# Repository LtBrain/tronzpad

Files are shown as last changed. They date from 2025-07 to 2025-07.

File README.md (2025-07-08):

# **Tronzpad**
Tronzpad is a 12 key + 1 encoder macropad that has 12 individually addressable LEDs to provide underglow & backlighting.
It was developed for an entry for **Hackclub Highway**'s YSWS project (Hackpad) and has the ability to perform **macros** and other
cool stuff with VIAL & QMK.

tronzpad 1 (1)

## Features
   - [x] **12 Cherry MX switches**  
   - [x] **EC-11 Rotary Encoder + Push Button**  
   - [x] **12 Individually Adressable SK6812 MINI LEDs**  
   - [x] **Custom QMK and VIAL Features**  
   - [x] **Powered By A XIAO RP2040**

## PCB

All of the circuitry and PCB design was done with KiCAD 8.0 on Windows 11

#### Schematic

tronzpad_sch-1  

#### PCB Design



Credits to Joe Scotto for the footprints.

## Firmware

QMK and VIAL are meant to be used on Tronzpad for firmware.
   - [x] **Customizable keymap and layout**
   - [x] **12 keys for macros**
   - [x] **Compilable with QMK MSYS on Win11 and Linux (MacOS not tested)**
   - [x] **Real-time/On the fly configuration**
   - [x] **Layer Switching**  
### **How to Compile the Firmware**  
```qmk compile -kb tronzpad -km default```  
  
Paste this into a **MSYS** terminal on Windows or into a Linux terminal with **QMK** already setup.  
(You have to be in the **directory** for this to work)

## Case Assembly
   The case for the Tronzpad was designed to be minimalistic, exposing the graphics on the PCB silkscreen. It is composed of two 3D printed parts, a plate piece and the main assembly.
   The case has 4 2.9mm holes designed to accommodate M3 screws to hold the PCB in place. The plate sits on top of the PCB's top layer to provide a cosmetic/semi-functional layer for 
   the switches to be seated in. 

   ### Plate
   ![tronzpad 1 (2)](https://github.com/user-attachments/assets/d26cf02f-f786-46ef-9ef3-2593b20badfe)

   ### Main Case
   ![tronzpad 1 (3)](https://github.com/user-attachments/assets/5db9a6ba-11bc-4787-be42-7c94eafe2cd0)

## Bill of Materials  

| Quantity | Component | Description |
| --- | --- | --- |
| `1` | **Seeed Studio XIAO RP2040** | MCU |
| `12` | **Cherry MX Keyswitches** | I/O |
| `1` | **EC11 Rotary Encoder** | I/O |
| `13` | **1N4148 Diodes** | Support |
| `15` | **SK6812 MINI LEDs** | I/O | 
| `12` | **DSA Keycaps** | Support |
| `4` | **M3x16mm Screws**| Support |
| `1` | **Case Plate**| Support |
| `1` | **Main Case**| Support |
| `1` | **PCB (From JLCPCB)**| Circuit |  

**Summer, 2025**

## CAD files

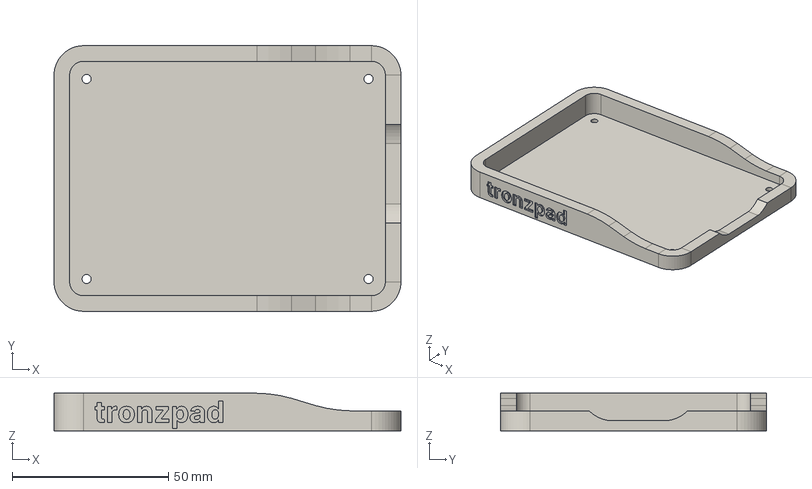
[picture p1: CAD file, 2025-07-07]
Production/tronzpad_main_case.step
111.0 x 85.0 x 12.0 mm

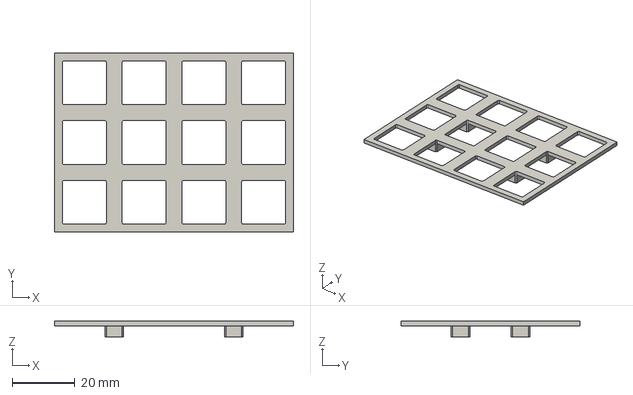
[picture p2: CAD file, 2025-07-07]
Production/tronzpad_plate.step
76.2 x 57.1 x 5.00 mm

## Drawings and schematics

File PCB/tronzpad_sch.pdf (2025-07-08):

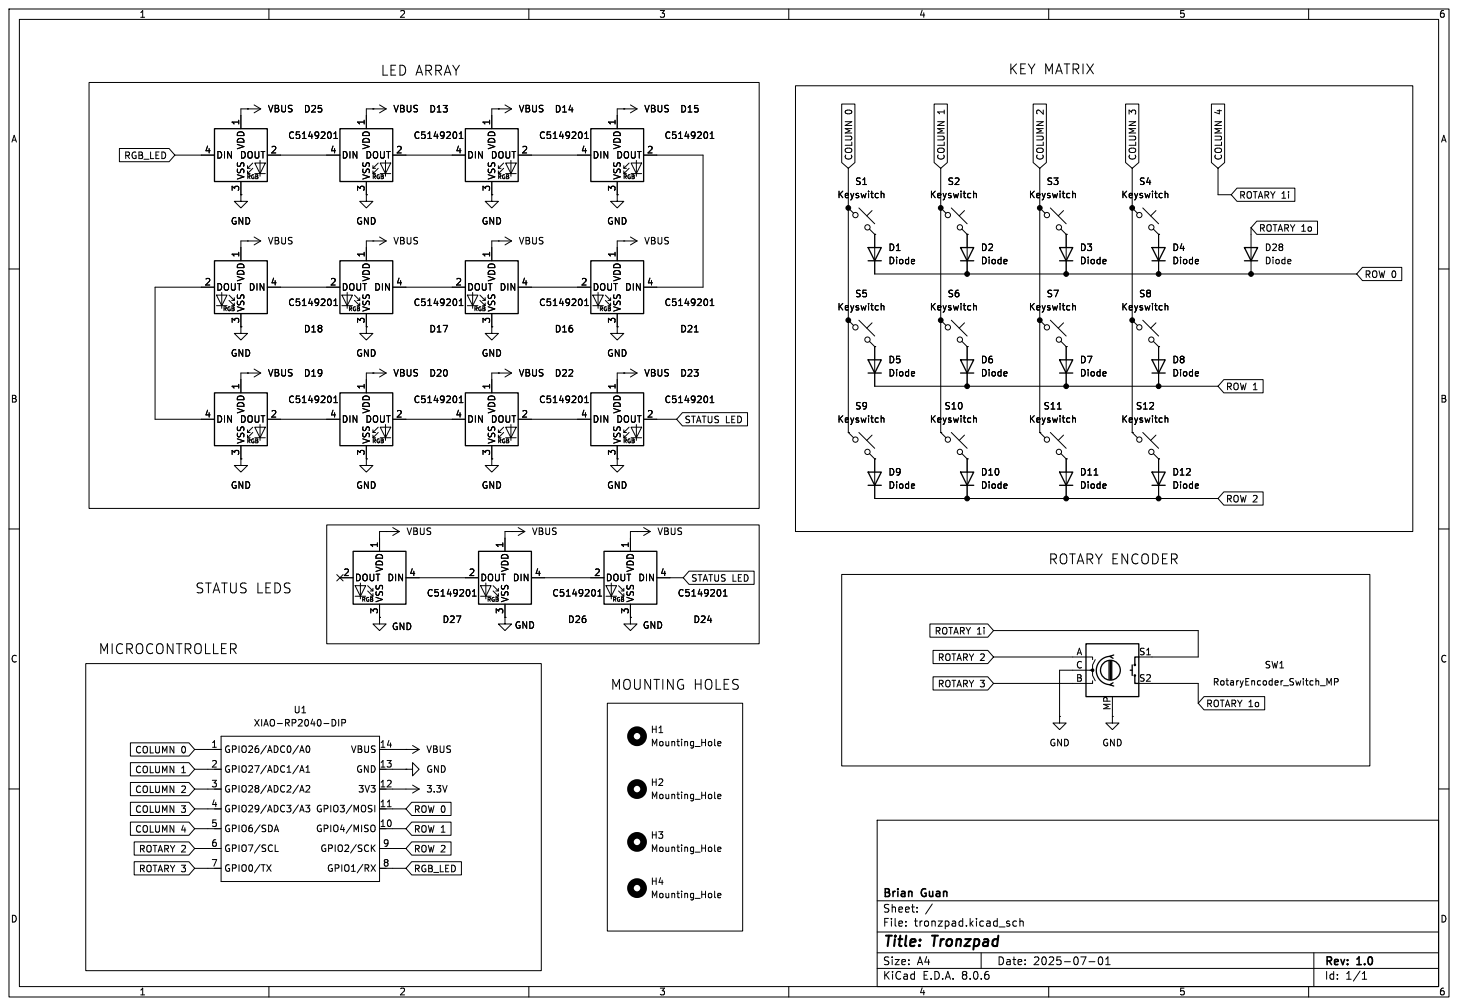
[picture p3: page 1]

3 DIN 4 D22 C5149201 S7 Keyswitch S8 Keyswitch COLUMN 1 ROTARY 3 ROTARY 2 COLUMN 4 COLUMN 3 COLUMN 4 ROW 0 ROW 2 COLUMN 3 COLUMN 1 COLUMN 2 COLUMN 0

3 DIN 4 D13 C5149201 D2 Diode S2 Keyswitch D28 Diode GND

3 DIN 4 D26 C5149201 GND GND GND GND

3 DIN 4 GND GND GND GND D26 C5149201 VDD

File: tronzpad.kicad_sch Sheet: / Brian Guan

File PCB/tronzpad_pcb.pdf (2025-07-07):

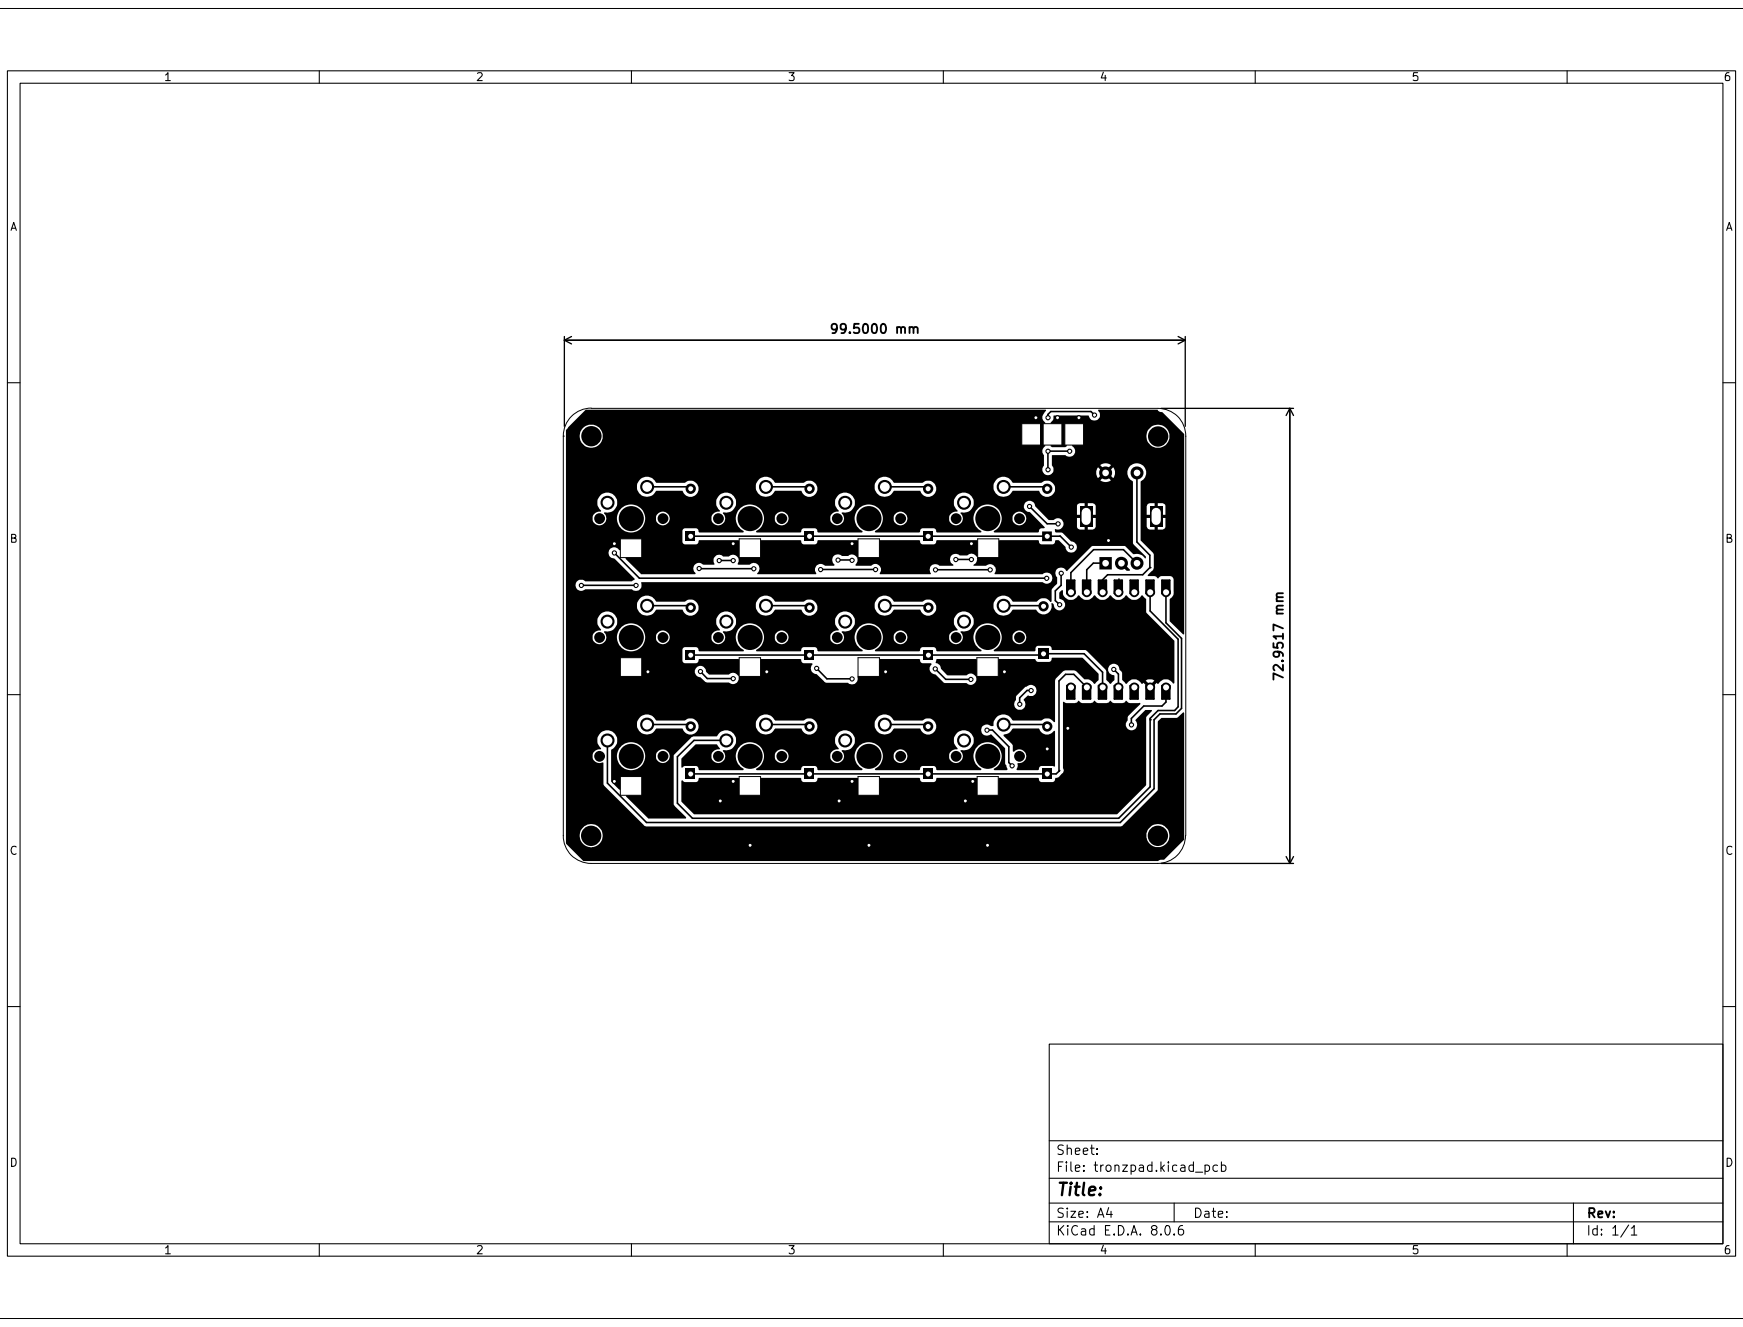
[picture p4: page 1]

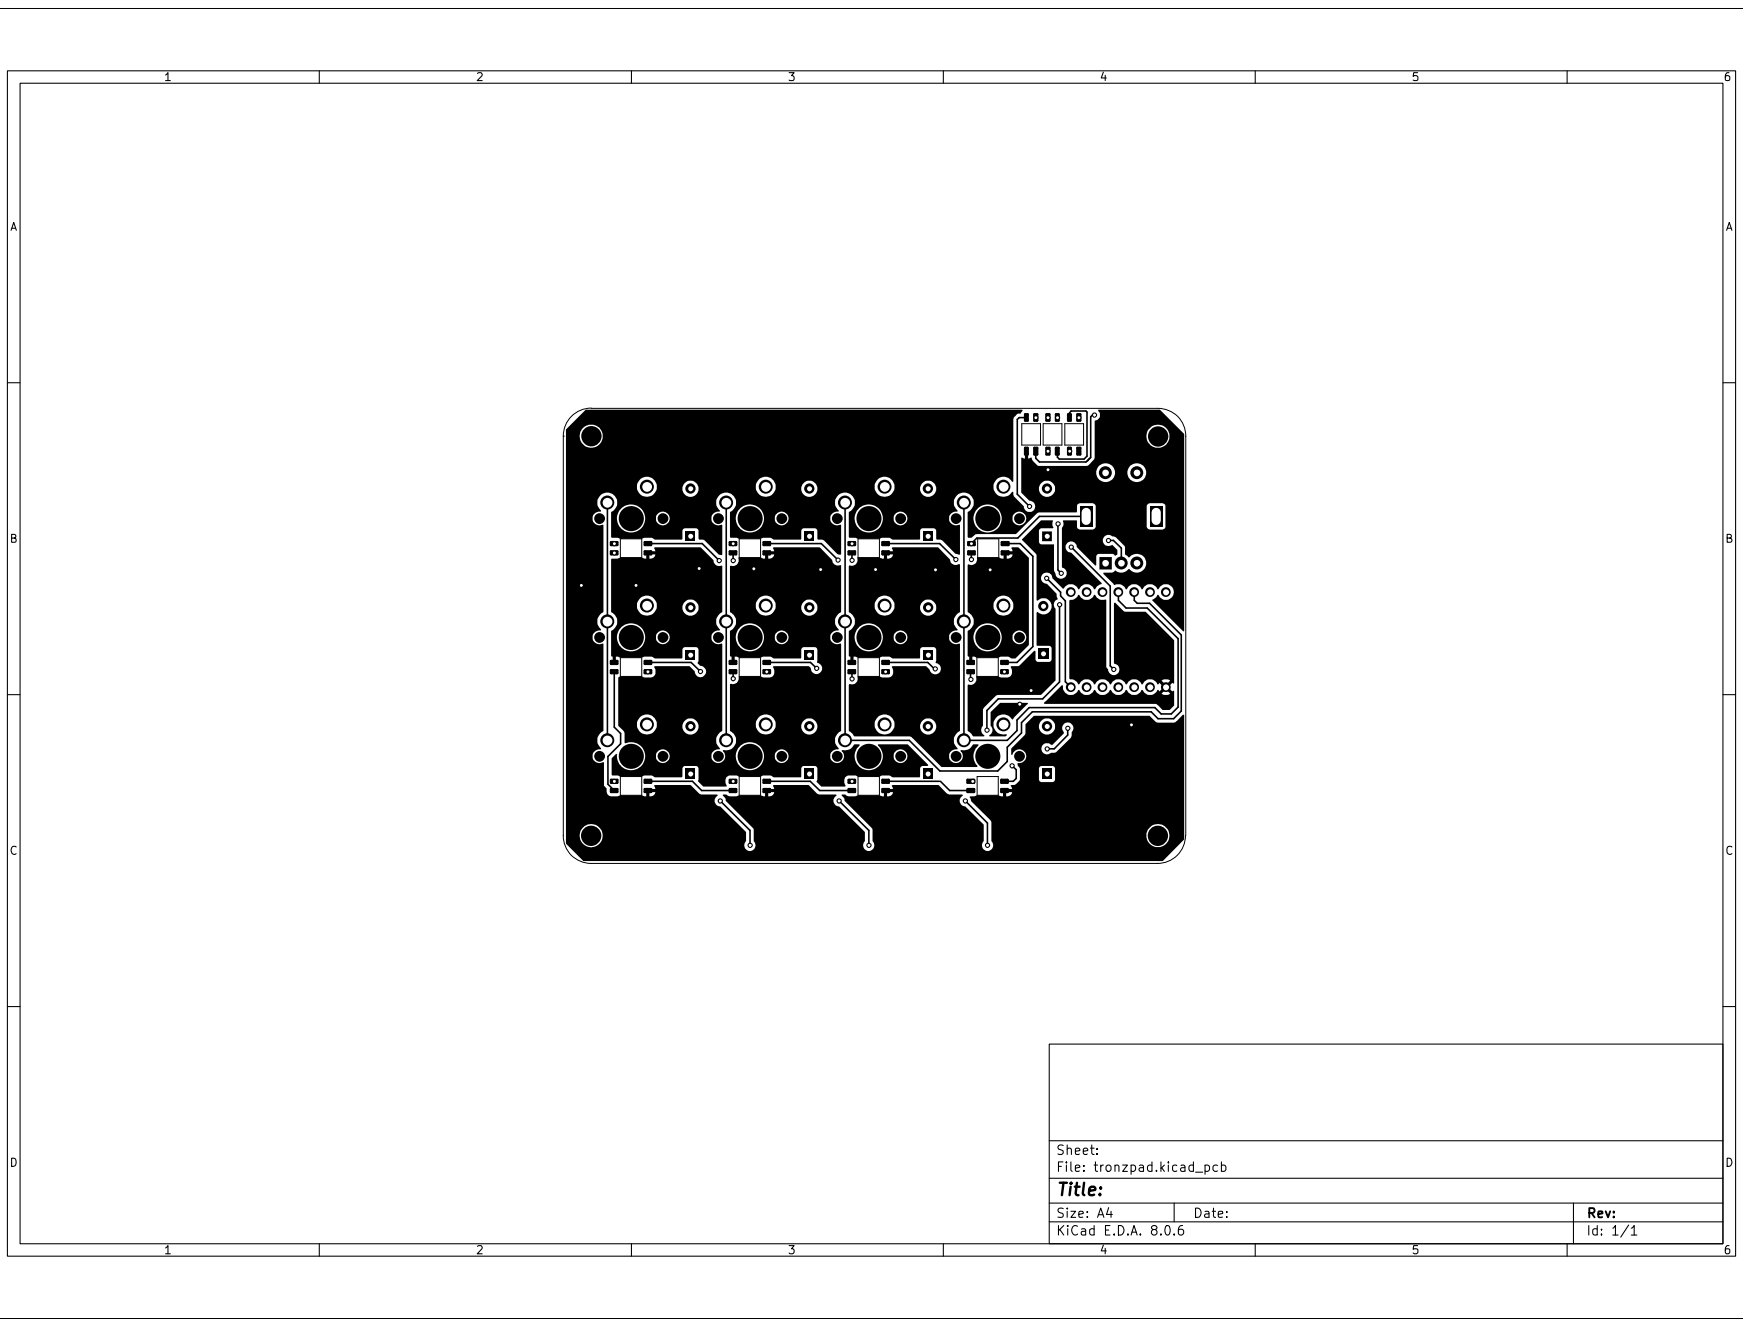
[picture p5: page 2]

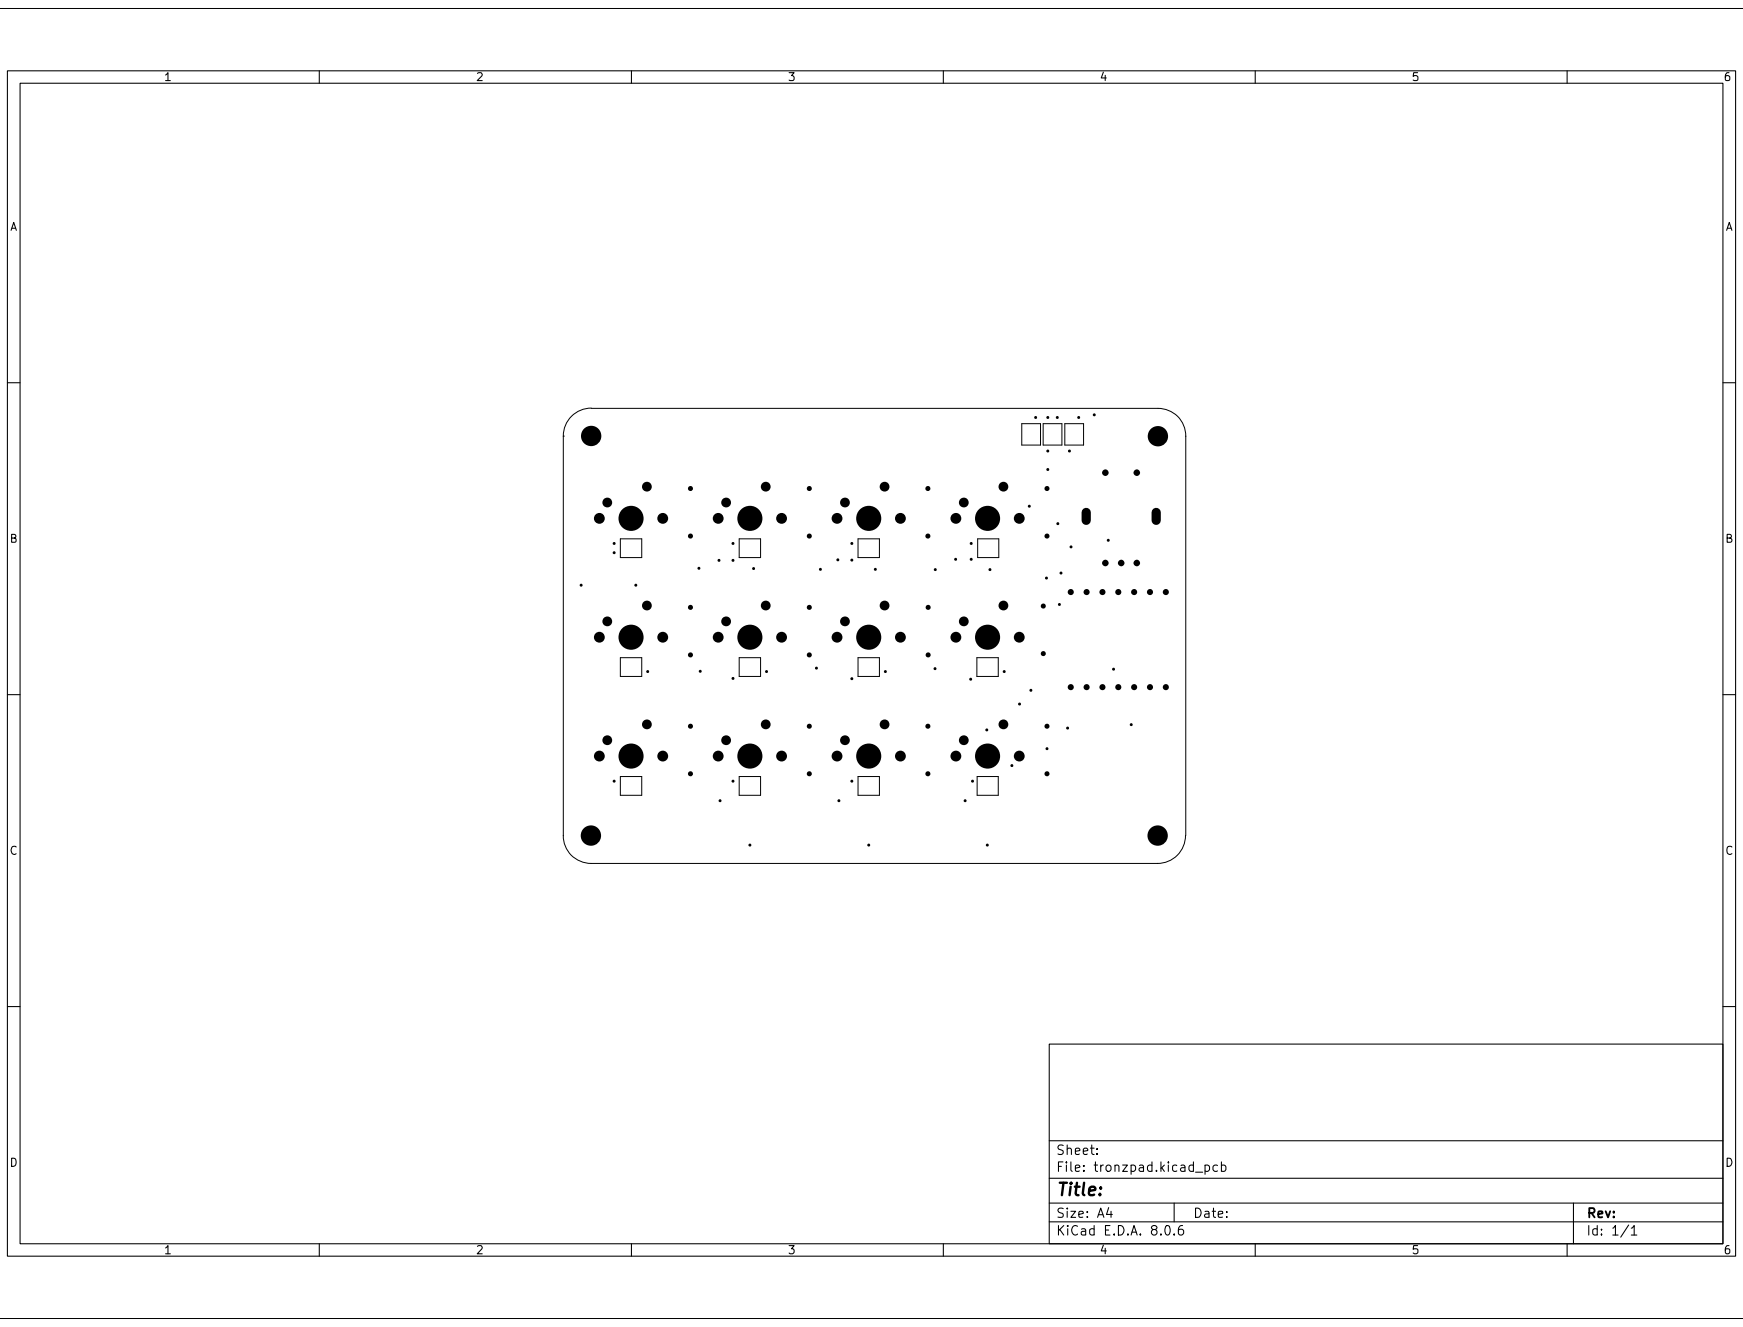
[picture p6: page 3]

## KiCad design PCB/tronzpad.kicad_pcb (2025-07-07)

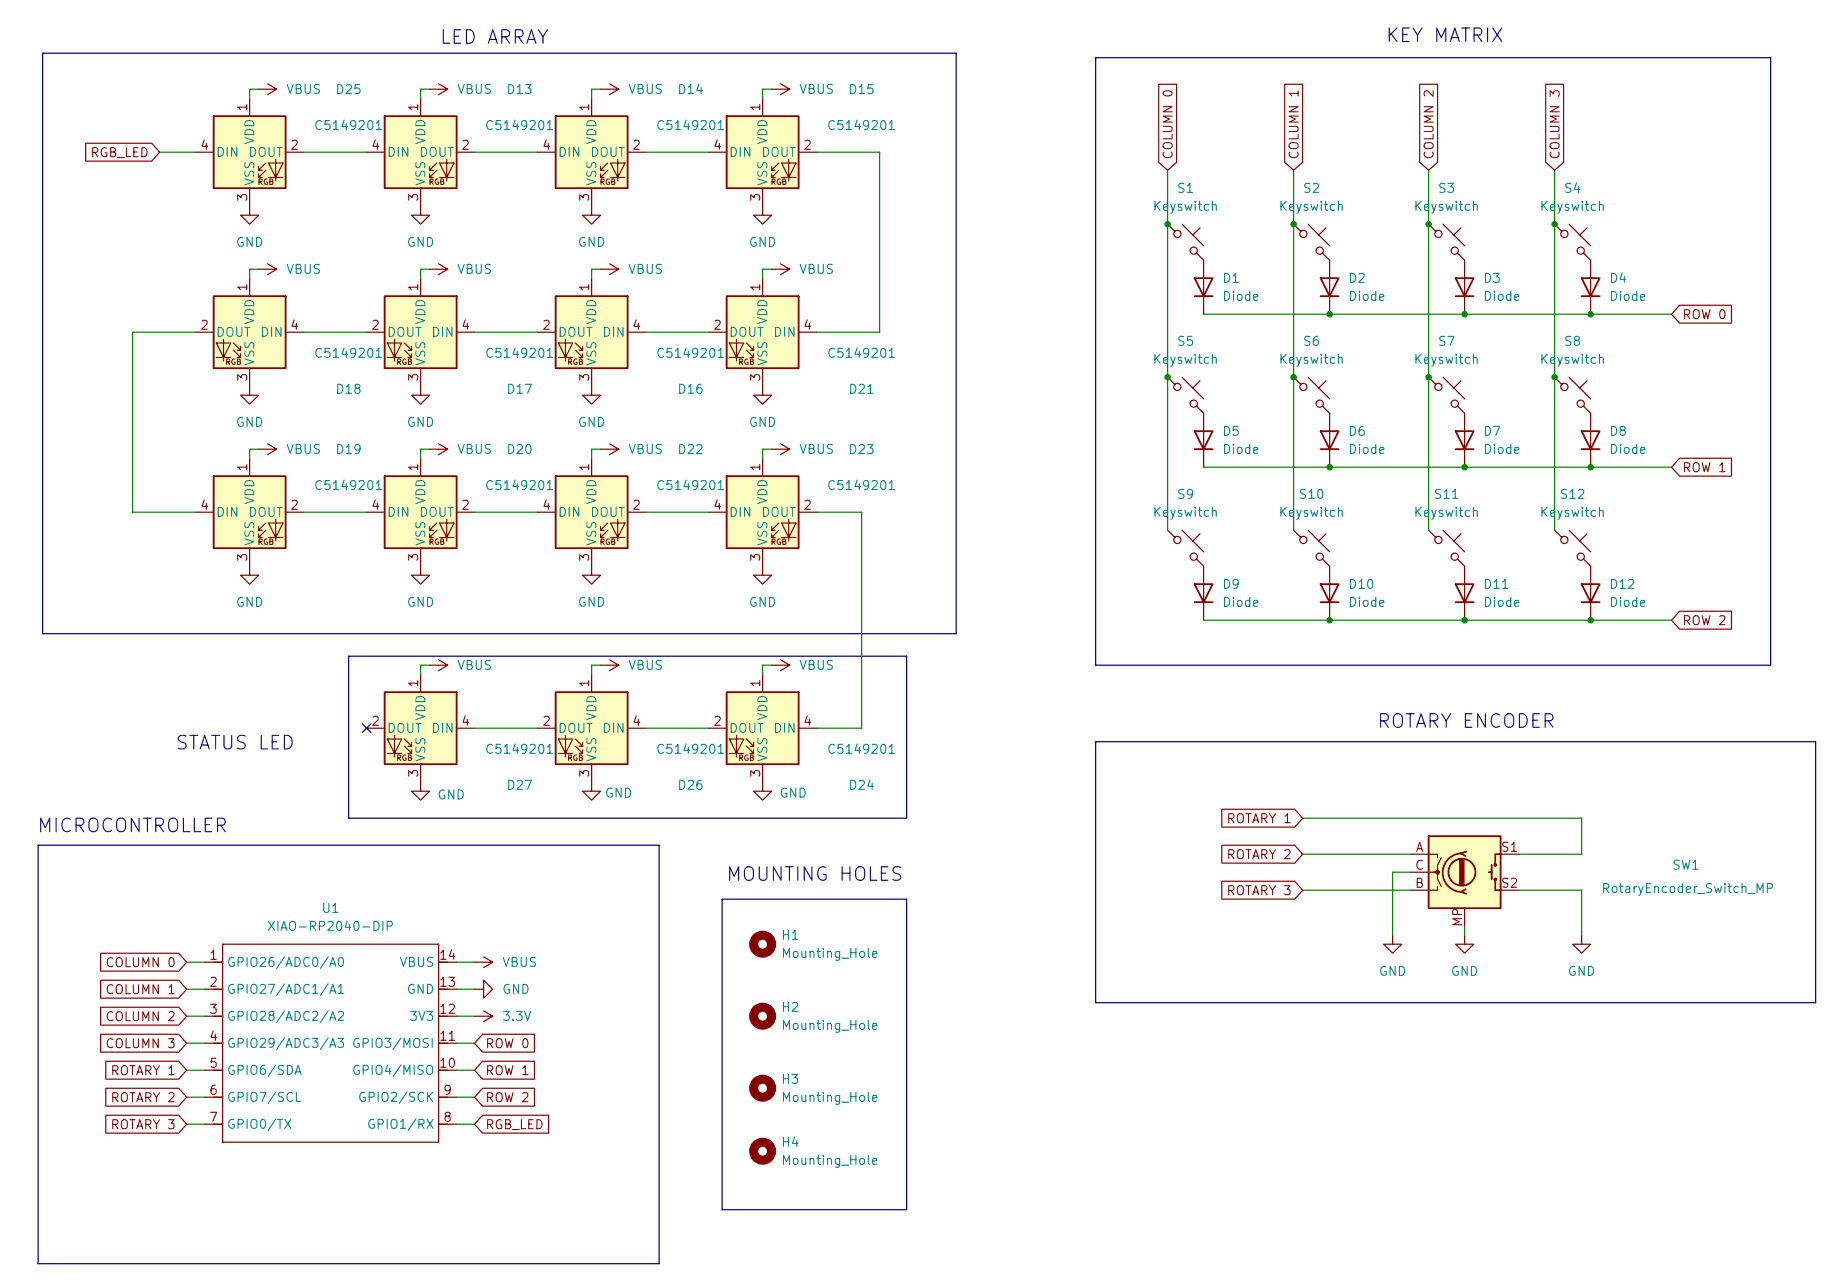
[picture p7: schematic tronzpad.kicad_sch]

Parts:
D1, D2, D3, D4, D5, D6, D7, D8, D9, D10, D11, D12: Diode; D_DO-35_SOD27_P7.62mm_Horizontal
D13, D14, D15, D16, D17, D18, D19, D20, D21, D22, D23, D24, D25, D26, D27: LED_SK6812MINI; LCSC C5149201
H1, H2, H3, H4: Mounting_Hole; MountingHole_3.2mm_M3_DIN965
S1, S2, S3, S4, S5, S6, S7, S8, S9, S10, S11, S12: Keyswitch; SW_Cherry_MX_1.00u_PCB
SW1: RotaryEncoder_Switch_MP; RotaryEncoder_Alps_EC11E-Switch_Vertical_H20mm
U1: XIAO-RP2040-DIP

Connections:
3.3V: U1.12 (3V3)
COLUMN 1: S1.2, S5.2, S9.2, U1.1 (GPIO26/ADC0/A0)
COLUMN 2: S2.2, S6.2, S10.2, U1.2 (GPIO27/ADC1/A1)
COLUMN 3: S3.2, S7.2, S11.2, U1.3 (GPIO28/ADC2/A2)
COLUMN 4: S4.2, S8.2, S12.2, U1.4 (GPIO29/ADC3/A3)
GND: D13.3 (VSS), D14.3 (VSS), D15.3 (VSS), D16.3 (VSS), D17.3 (VSS), D18.3 (VSS), D19.3 (VSS), D20.3 (VSS), D21.3 (VSS), D22.3 (VSS), D23.3 (VSS), D24.3 (VSS), D25.3 (VSS), D26.3 (VSS), D27.3 (VSS), SW1.C, SW1.MP, SW1.S2, U1.13 (GND)
unnamed: D1.2 (A), S1.1
unnamed: D2.2 (A), S2.1
unnamed: D3.2 (A), S3.1
unnamed: D4.2 (A), S4.1
unnamed: D5.2 (A), S5.1
unnamed: D6.2 (A), S6.1
unnamed: D7.2 (A), S7.1
unnamed: D8.2 (A), S8.1
unnamed: D9.2 (A), S9.1
unnamed: D10.2 (A), S10.1
unnamed: D11.2 (A), S11.1
unnamed: D12.2 (A), S12.1
unnamed: D13.4 (DIN), D25.2 (DOUT)
unnamed: D13.2 (DOUT), D14.4 (DIN)
unnamed: D14.2 (DOUT), D15.4 (DIN)
unnamed: D15.2 (DOUT), D21.4 (DIN)
unnamed: D16.4 (DIN), D21.2 (DOUT)
unnamed: D16.2 (DOUT), D17.4 (DIN)
unnamed: D17.2 (DOUT), D18.4 (DIN)
unnamed: D18.2 (DOUT), D19.4 (DIN)
unnamed: D19.2 (DOUT), D20.4 (DIN)
unnamed: D20.2 (DOUT), D22.4 (DIN)
unnamed: D22.2 (DOUT), D23.4 (DIN)
unnamed: D23.2 (DOUT), D24.4 (DIN)
unnamed: D24.2 (DOUT), D26.4 (DIN)
unnamed: D26.2 (DOUT), D27.4 (DIN)
RGB_LED: D25.4 (DIN), U1.8 (GPIO1/RX)
ROTARY 1: SW1.S1, U1.5 (GPIO6/SDA)
ROTARY 2: SW1.A, U1.6 (GPIO7/SCL)
ROTARY 3: SW1.B, U1.7 (GPIO0/TX)
ROW 1: D1.1 (K), D2.1 (K), D3.1 (K), D4.1 (K), U1.11 (GPIO3/MOSI)
ROW 2: D5.1 (K), D6.1 (K), D7.1 (K), D8.1 (K), U1.10 (GPIO4/MISO)
ROW 3: D9.1 (K), D10.1 (K), D11.1 (K), D12.1 (K), U1.9 (GPIO2/SCK)
VBUS: D13.1 (VDD), D14.1 (VDD), D15.1 (VDD), D16.1 (VDD), D17.1 (VDD), D18.1 (VDD), D19.1 (VDD), D20.1 (VDD), D21.1 (VDD), D22.1 (VDD), D23.1 (VDD), D24.1 (VDD), D25.1 (VDD), D26.1 (VDD), D27.1 (VDD), U1.14 (VBUS)

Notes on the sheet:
ROTARY ENCODER
LED ARRAY
MOUNTING HOLES
MICROCONTROLLER
STATUS LED
KEY MATRIX

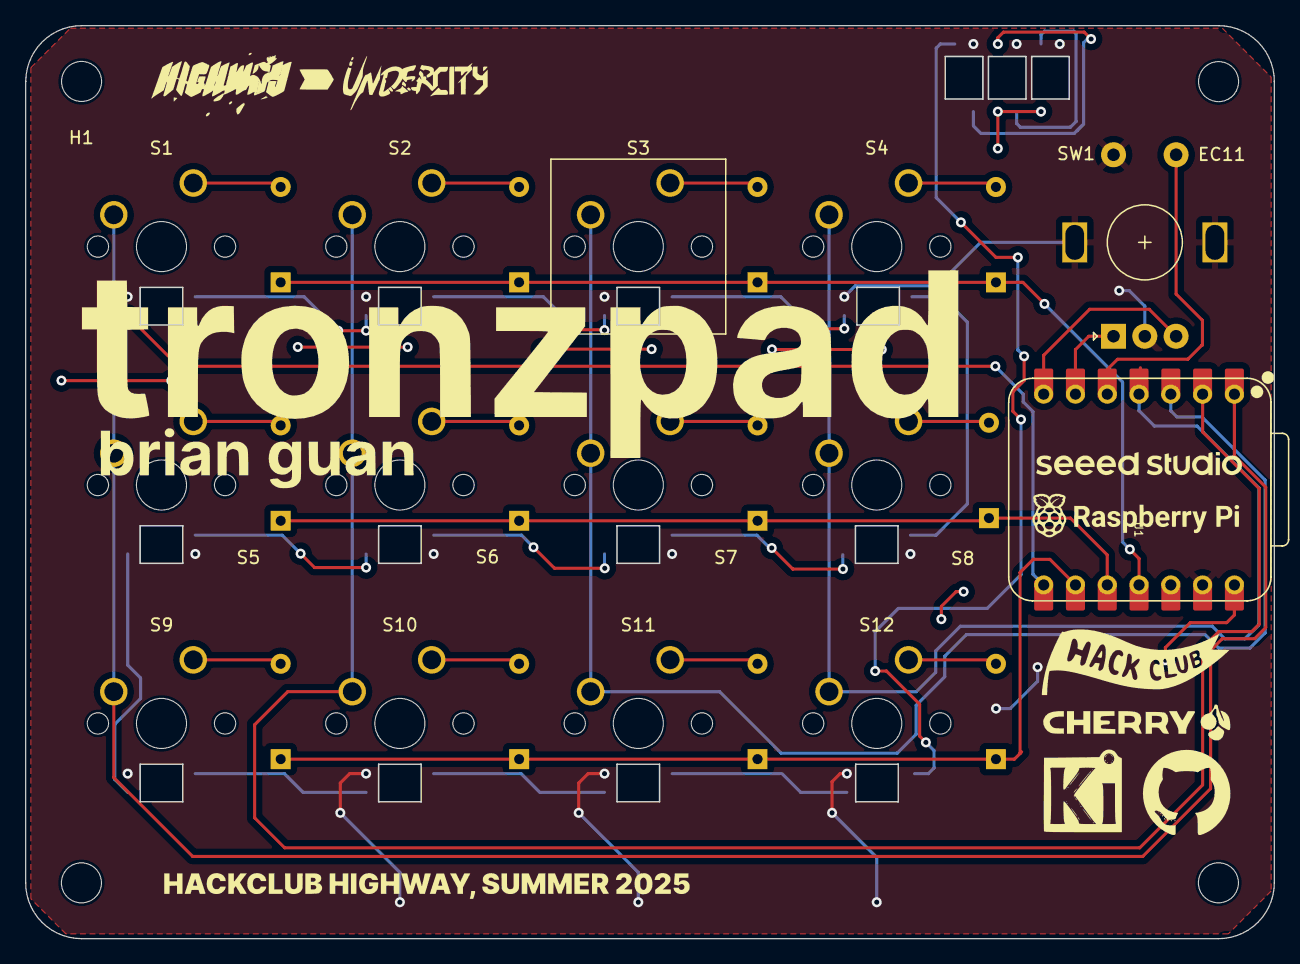
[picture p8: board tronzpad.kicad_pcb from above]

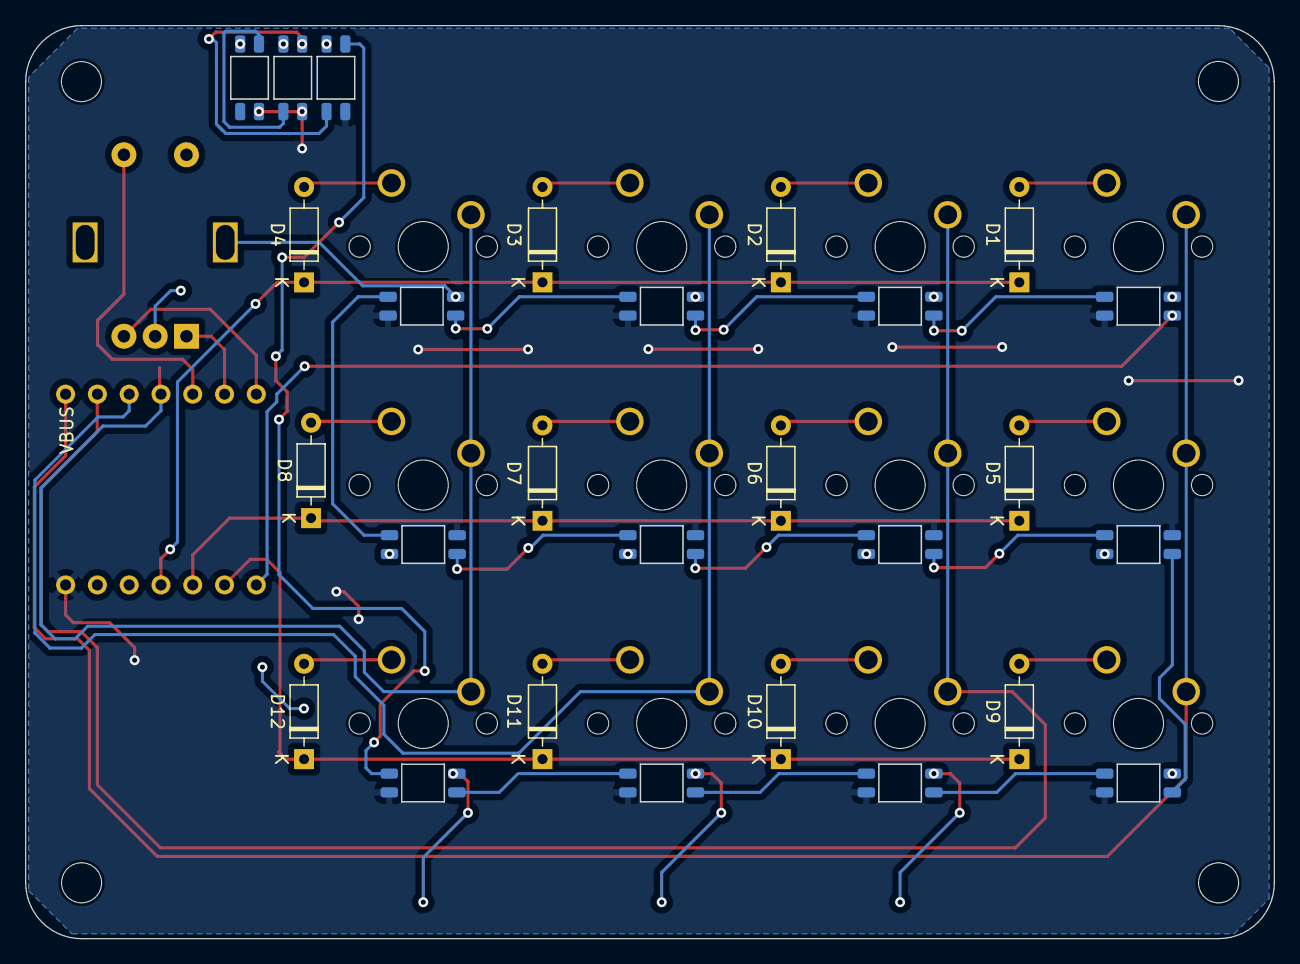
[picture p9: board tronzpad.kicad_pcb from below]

Board: 2 copper layers, 99.8 x 73.0 mm, 45 parts (27 on the bottom side), 39 nets.

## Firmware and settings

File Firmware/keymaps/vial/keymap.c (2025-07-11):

// Copyright 2023 QMK
// SPDX-License-Identifier: GPL-2.0-or-later

#include QMK_KEYBOARD_H

// Toggle for 12-key backlight
static bool backlight_on = false;

const uint16_t PROGMEM keymaps[][MATRIX_ROWS][MATRIX_COLS] = {
    /*
     * ┌───┬───┬───┬───┐  ┌───┐
     * │ 1 │ 2 │ 3 │ 4 │ ││DF1││
     * ├───┼───┼───┼───┤  └───┘ 
     * │ 5 │ 6 │ 7 │ 8 │
     * ├───┼───┼───┼───┤
     * │ 9 │ 0 │SPC│ENT│
     * └───┴───┴───┴───┘ 
    */
    [0] = LAYOUT(
        KC_1,   KC_2,   KC_3,   KC_4, DF(1),
        KC_5,   KC_6,   KC_7,   KC_8,
        KC_9,   KC_0,   KC_SPC, KC_ENTER
    ),
    /*
     * ┌───┬───┬───┬───┐  ┌───┐
     * │ Q │ W │ E │ R │ ││DF2││
     * ├───┼───┼───┼───┤  └───┘ 
     * │ A │ S │ D │ F │
     * ├───┼───┼───┼───┤
     * │ Z │ X │ C │ F │
     * └───┴───┴───┴───┘ 
    */
    [1] = LAYOUT(
        KC_Q,   KC_W,   KC_E,   KC_R, DF(2),
        KC_A,   KC_S,   KC_D,   KC_F,
        KC_Z,   KC_X,   KC_C,   KC_F
    ),
    /*
     * ┌───┬───┬───┬───┐  ┌───┐
     * │ CP│CAL│SLP│HOM│ ││DF0││
     * ├───┼───┼───┼───┤  └───┘ 
     * │MUT│MPL│SEL│WSC│
     * ├───┼───┼───┼───┤
     * │F13│F14│F15│F16│
     * └───┴───┴───┴───┘ 
    */
    [2] = LAYOUT(
        KC_CONTROL_PANEL,   KC_CALC,   KC_SYSTEM_SLEEP,   KC_HOME, DF(0),
        KC_MUTE,            KC_MPLY,   KC_MSEL,           KC_WSCH,
        KC_F13,             KC_F14,    KC_F15,            KC_F16
    )
};

bool process_record_user(uint16_t keycode, keyrecord_t *record) {
    if (keycode == KC_F13 && record->event.pressed) {
        backlight_on = !backlight_on;
        return false;
    }
    return true;
}

bool rgb_matrix_indicators_user(void) {
    // Toggle backlight for 12 key LEDs
    for (int i = 0; i < 12; i++) {
        if (backlight_on) {
            rgb_matrix_set_color(i, 120, 80, 40); // amber color
        } else {
            rgb_matrix_set_color(i, 0, 0, 0);     // off
        }
    }

    // Turn off all status LEDs first
    rgb_matrix_set_color(12, 0, 0, 0);
    rgb_matrix_set_color(13, 0, 0, 0);
    rgb_matrix_set_color(14, 0, 0, 0);

    // Amber indicates the layer selected, pastel orange to count
    switch (get_highest_layer(layer_state)) {
        case 0:
            rgb_matrix_set_color(12, 255, 191, 0);   // Amber
            break;
        case 1:
            rgb_matrix_set_color(12, 255, 192, 103); // Pastel Orange
            rgb_matrix_set_color(13, 255, 191, 0);   // Amber 
            break;
        case 2:
            rgb_matrix_set_color(12, 255, 192, 103); // Pastel Orange
            rgb_matrix_set_color(13, 255, 192, 103); // Pastel Orange
            rgb_matrix_set_color(14, 255, 191, 0);   // Amber
            break;
        default:
            break;
    }

    return true;
}

// EC11 Rotary Encoder  
#if defined(ENCODER_MAP_ENABLE)
const uint16_t PROGMEM encoder_map[][NUM_ENCODERS][NUM_DIRECTIONS] = {
    [0] = { ENCODER_CCW_CW(KC_VOLD, KC_VOLU) },
    [1] = { ENCODER_CCW_CW(RM_VALD, RM_SPDU) },
    [2] = { ENCODER_CCW_CW(RM_HUED, RM_HUEU) } 
};
#endif

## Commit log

2025-07-02 add folders & commit kicad files
    [tronzpad.kicad_pcb, tronzpad.kicad_sch]
2025-07-02 add schematic pdf rev1
2025-07-03 add gerbers
    [tronzpad-B_Cu.gbr, tronzpad-B_Mask.gbr, tronzpad-B_Paste.gbr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]
2025-07-03 add gerber.zip
    [tronzpad-B_Cu.gbr, tronzpad-B_Mask.gbr, tronzpad-B_Paste.gbr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]
2025-07-05 more pcb and schematic changes
    [tronzpad-B_Cu.gbr, tronzpad-B_Mask.gbr, tronzpad-B_Paste.gbr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]
2025-07-06 add CAD model for entire hackpad
    [tronzpadv1.step]
2025-07-06 remove unneccessary pcb files and add pcb pdf
2025-07-07 add loads of stuff to production
    [tronzpad-B_Cu.gbr, tronzpad-B_Mask.gbr, tronzpad-B_Paste.gbr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]
2025-07-09 encoder and VID/PID addition to firmware
